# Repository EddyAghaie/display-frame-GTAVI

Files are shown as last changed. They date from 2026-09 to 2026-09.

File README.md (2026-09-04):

# display-frame-GTAVI
DIY PlayStation Gaming Wall Art made with a printed game cover, deep A4 picture frame, custom GIF player, 3D-printed disc holder, action figure, and printable game disc. Build your own unique gaming decoration with your favorite game. All 3D print files and project files are included in this repository.

# PlayStation Gaming Wall Art

<p align="center">
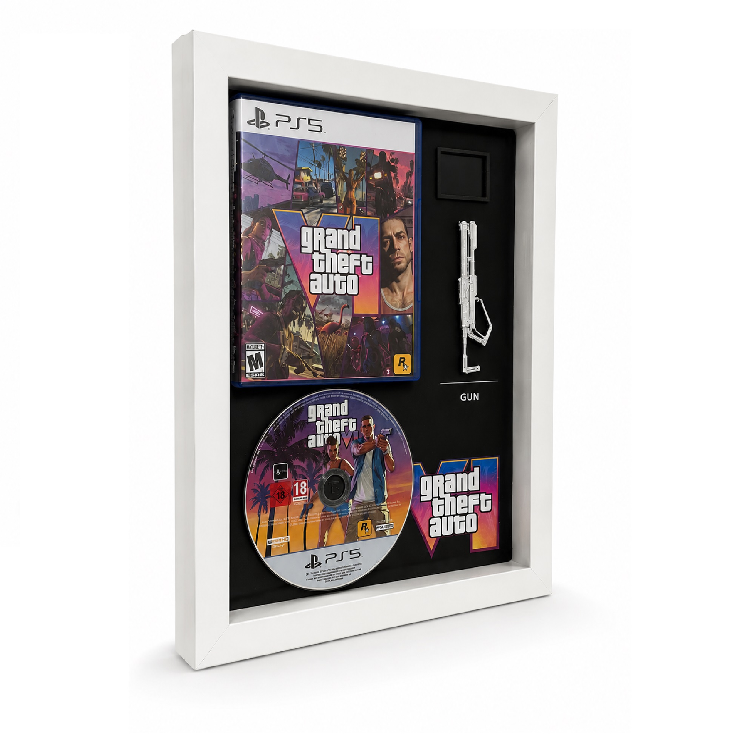
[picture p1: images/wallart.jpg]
  
</p>

DIY PlayStation Gaming Wall Art...
A DIY gaming wall art project made from a PlayStation game case, a printed game cover, a GIF player, and 3D-printed parts.

This project turns a simple game case into a unique gaming decoration with a small display that can play your favorite GIFs.

## Features

* PlayStation game case design
* Custom printed game cover
* Small GIF player with display
* 3D-printed disc holder
* 3D-printed action figure holder
* Custom printed game disc
* A4 deep picture frame
* Custom printed background
* Easy to build
* Low-cost project

## What You Need

* 1× PlayStation game case
* 1× Printed game cover — 270 × 166 mm
* 1× Printable game disc
* 1× GIF player
* 1× A4 deep picture frame
* 1× Printed game background
* 1× 3D-printed disc holder
* 1× 3D-printed action figure
* Double-sided tape
* Glue

## GIF Player

The GIF player is based on an ESP32 and a small display.

You can find the complete GIF player project, including the code, PCB files, wiring, and other files, in my previous GitHub project.

## 3D Print Files

All the 3D-printable files for this project are included in this repository.

You can download the files, print the parts, and build your own gaming wall art.

## Assembly

The project is made in a few simple steps:

1. Print the game cover.
2. Prepare the PlayStation game case.
3. Assemble the printed cover and game case.
4. Prepare the A4 picture frame.
5. Cut the display opening in the back of the frame.
6. Attach the printed background.
7. Install the GIF player.
8. Add the 3D-printed parts.
9. Assemble everything together.
10. Add your favorite game disc and action figure.

## Cost

The project is designed to be low-cost and easy to build.

The GIF player itself costs less than **$6** to build, depending on the components and prices in your area.

## Customize Your Project

You can use any PlayStation game you like.

Change the game cover, background, disc, GIFs, and action figure to create your own custom gaming wall art.

## Files

This repository includes:

* 3D print files
* Game cover template
* Background files
* Printable disc files
* Assembly files
* Project images
* Instructions

## Video Tutorial

Watch the full build video on my YouTube channel to see how I made this project from start to finish.

**EDDYSTUDIO_LAB**

If you build your own version, feel free to share it!

## License

This project is provided for personal and educational use.

Please check the licenses of any third-party game artwork, characters, logos, or other copyrighted materials before redistributing or selling your own version.

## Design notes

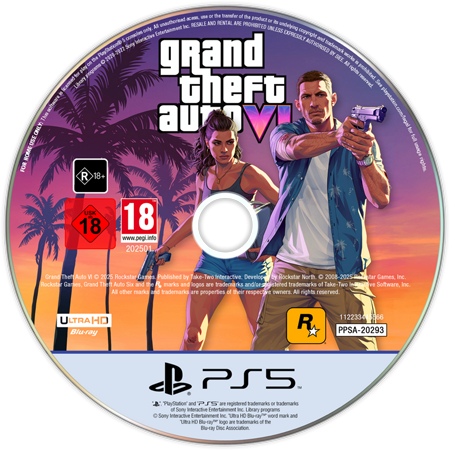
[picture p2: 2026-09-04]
GTA VI IMAGE: PRINT FILE/gta6-ps5-disc-fan-mad-concept-s.png

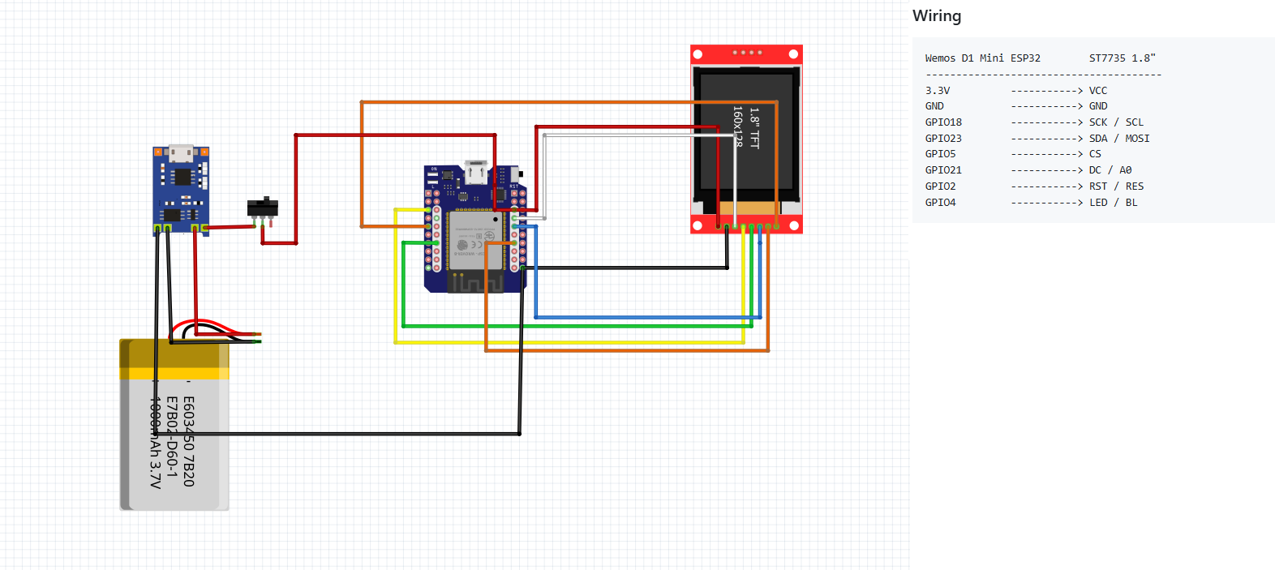
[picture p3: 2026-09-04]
GIFPLAYER/schema.PNG

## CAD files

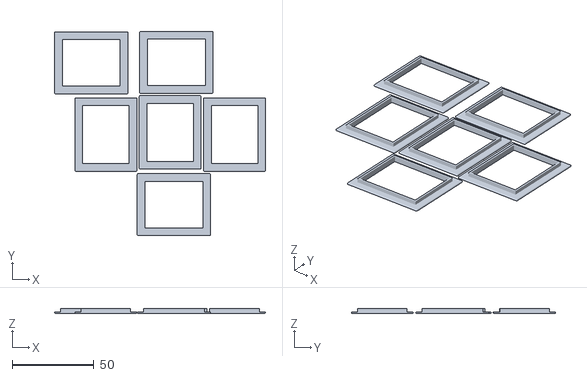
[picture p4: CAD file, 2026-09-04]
3DFILE/frame.stl
129.3 x 125.2 x 3.00

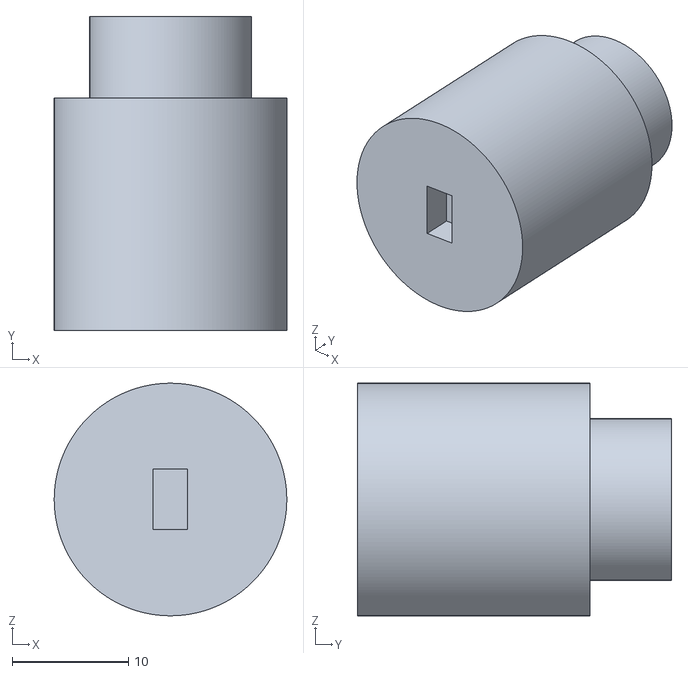
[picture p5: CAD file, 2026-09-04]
3DFILE/ring cd.stl
20.0 x 27.0 x 20.0

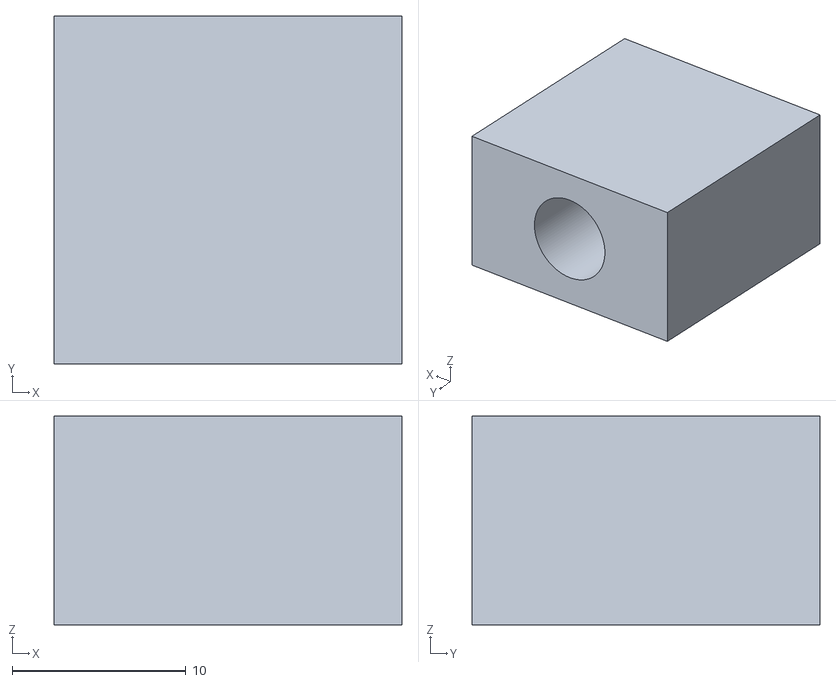
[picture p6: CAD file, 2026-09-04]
3DFILE/stand hole.stl
20.0 x 20.0 x 12.0

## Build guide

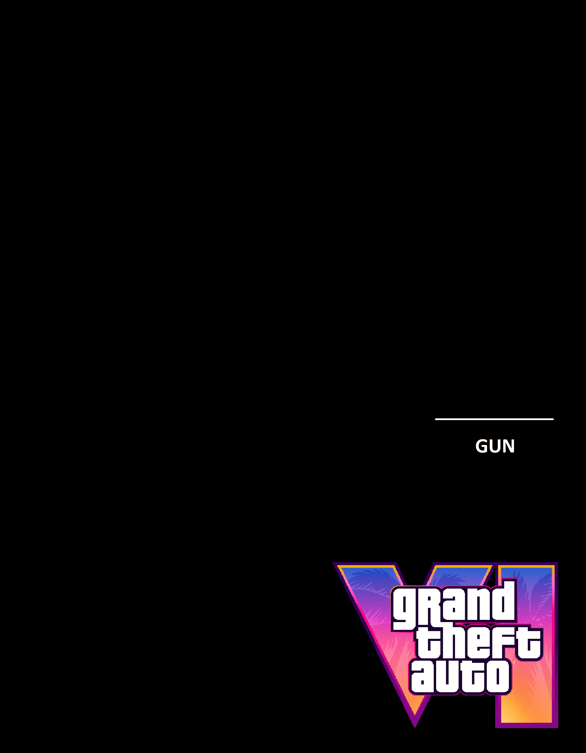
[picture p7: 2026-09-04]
GTA VI IMAGE: PRINT FILE/background.png

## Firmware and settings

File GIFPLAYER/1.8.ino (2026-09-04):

/*
  ====================================================================
  GifFrame - ESP32 + ST7735 1.8" (160x128 Landscape) WiFi Image/GIF Frame
  ====================================================================
  پین‌بندی نهایی:
    SDA (MOSI) = GPIO23
    SCK        = GPIO18
    CS         = GPIO5
    LED (BL)   = GPIO4
    RESET      = GPIO2
    DC         = GPIO21
    VCC -> 3.3V , GND -> GND

  کتابخانه‌های لازم (از Library Manager نصب کنید):
    - Adafruit GFX Library
    - Adafruit ST7735 and ST7789 Library (+ Adafruit BusIO)
    - ESPAsyncWebServer + AsyncTCP  (فورک ESP32Async از گیت‌هاب - ZIP)
    - LittleFS (داخل هسته ESP32)
    - Preferences (داخل هسته ESP32)
    - QRCodeGen.h / QRCodeGen.c (کنار فایل .ino - فایل‌های ricmoo/QRCode با اصلاح bool)

  نکته: AnimatedGIF دیگر لازم نیست. پردازش/ریسایز کاملاً سمت گوشی
        با جاوااسکریپت خالص (بدون نیاز به اینترنت/CDN) انجام می‌شود
        و یک فرمت باینری سبک سفارشی به نام "GFA1" به دستگاه ارسال می‌شود.

  منطق کلی:
    1) بوت اول (هیچ فایلی ذخیره نشده): صفحه QR1 با پس‌زمینه سفید نشان داده
       می‌شود - برای اتصال خودکار گوشی به وای‌فای دستگاه (بدون پسورد).
    2) به محض اتصال یک کلاینت به AP (رویداد WiFi)، صفحه به QR2 با پس‌زمینه
       قرمز تغییر می‌کند که آدرس "http://192.168.4.1/" را کد کرده -
       با اسکن، صفحه تنظیمات مستقیماً در مرورگر گوشی باز می‌شود (بدون
       نیاز به Captive Portal، که در iOS محدودیت‌های زیادی دارد).
    3) صفحه‌ی وب: آپلود هر عکس/گیف از گالری گوشی + راهنمای انگلیسی برای
       افزودن به Home Screen یا ذخیره آدرس 192.168.4.1.
       مرورگر خودش عکس/گیف رو دیکود، cover (پر کردن کامل صفحه بدون فضای
       خالی) به 160x128 ریسایز، و به فرمت "GFA1" (هدر + فریم‌های RGB565
       خام) تبدیل و آپلود می‌کند.
    4) ESP32 فایل "/current.anim" را ذخیره و به‌صورت لوپ دائم پخش می‌کند؛
       از این لحظه صفحات QR دیگر نمایش داده نمی‌شوند.
    5) فکتوری ریست: شمارش 5 بار روشن/خاموش در بازه 10 ثانیه با Preferences (NVS)
       -> پاک کردن LittleFS و ریست تنظیمات (برگشت به صفحه QR1).

  فرمت فایل "/current.anim" (GFA1):
    بایت 0-3   : "GFA1"
    بایت 4-5   : width  (uint16, little-endian) -> باید برابر SCREEN_W باشد
    بایت 6-7   : height (uint16, little-endian) -> باید برابر SCREEN_H باشد
    بایت 8-9   : frameCount (uint16, little-endian)
    سپس به ازای هر فریم:
      2 بایت delay_ms (uint16, little-endian)
      width*height*2 بایت پیکسل RGB565 (هر پیکسل 2 بایت big-endian/wire order)

  ====================================================================
*/

#include <SPI.h>
#include <Adafruit_GFX.h>
#include <Adafruit_ST7735.h>
#include <FS.h>
#include <LittleFS.h>
#include <WiFi.h>
#include <ESPAsyncWebServer.h>
#include <Preferences.h>
#include "QRCodeGen.h" // کتابخانه QRCode (ricmoo) - فایل‌های QRCodeGen.h/.c باید کنار .ino باشن

// ---------------- پین‌بندی ----------------
#define TFT_CS   5
#define TFT_DC   21
#define TFT_RST  2
#define TFT_LED  4
// MOSI=23 (SDA), SCK=18 -> پیش‌فرض HSPI/VSPI روی ESP32 همین‌ها هستند

#define SCREEN_W 160
#define SCREEN_H 128

// اگر تصویر روی نمایشگر شیفت/کراپ/wrap شده دیده شد، این مقادیر را تغییر بده.
// 2,1 رایج‌ترین مقدار برای پنل‌های 1.8" ST7735 (132x162 GRAM روی پنل 128x160) است.
// مقادیر دیگری که می‌توان امتحان کرد: (0,0), (2,3), (1,2), (3,2), (4,0)
// با کد اولیه (offset=0,0) تصاویر کامل و بدون موج/کجی نمایش داده می‌شدن.
// تغییر این مقادیر باعث موج‌دار/کج‌شدن تصویر می‌شود - دست نزنید مگر مطمئن باشید.
#define COL_START 0
#define ROW_START 0

// X_OFFSET/Y_OFFSET برای تنظیم ریز (fine-tuning) اضافه، معمولاً 0 بماند.
#define X_OFFSET 0
#define Y_OFFSET 0

// کلاس کوچک مشتق‌شده فقط برای دسترسی به setColRowStart که در کتابخونه protected است
class Adafruit_ST7735_Custom : public Adafruit_ST7735 {
public:
  Adafruit_ST7735_Custom(int8_t cs, int8_t dc, int8_t rst) : Adafruit_ST7735(cs, dc, rst) {}
  void setOffset(int8_t col, int8_t row) { setColRowStart(col, row); }
};

Adafruit_ST7735_Custom tft = Adafruit_ST7735_Custom(TFT_CS, TFT_DC, TFT_RST);
AsyncWebServer server(80);
Preferences prefs;

String apSSID;

// از بخش پخش (پایین‌تر تعریف می‌شود) - برای جلوگیری از دست‌کاری صفحه در حین پخش فریم
extern volatile bool animPlaying;

// ====================================================================
//                     ۱) FACTORY RESET LOGIC
// ====================================================================
// با 5 بار روشن/خاموش در بازه 10 ثانیه از حافظه NVS، ریست فکتوری انجام می‌شود.
void checkFactoryReset() {
  prefs.begin("sysinfo", false);
  uint8_t bootCount = prefs.getUChar("bootcnt", 0);

  bootCount++;
  if (bootCount >= 5) {
    Serial.println("== FACTORY RESET TRIGGERED ==");
    prefs.putUChar("bootcnt", 0);
    prefs.end();

    // پاک کردن کامل LittleFS (شامل فریم فعال و تنظیمات)
    LittleFS.format();

    tft.fillScreen(ST77XX_BLACK);
    tft.setTextColor(ST77XX_WHITE);
    tft.setTextSize(1);
    tft.setCursor(10, 60);
    tft.println("Factory Reset...");
    delay(1500);
    ESP.restart();
    return;
  }

  prefs.putUChar("bootcnt", bootCount);
  prefs.end();
}

void resetBootCounterAfterTimeout() {
  static unsigned long startTime = millis();
  static bool done = false;
  if (!done && millis() - startTime > 10000) {
    prefs.begin("sysinfo", false);
    prefs.putUChar("bootcnt", 0);
    prefs.end();
    done = true;
  }
}

// ====================================================================
//                     ۲) صفحات QR (Landscape) - دو مرحله‌ای
// ====================================================================
// QR_VERSION=4 برای هر دو متن (WiFi config و URL) کافی است.
// سایز بافر = ((4*version+17)^2 + 7) / 8  ->  برای version=4: ((33*33)+7)/8 = 137
#define QR_VERSION 4
#define QR_BUFFER_SIZE 137
uint8_t qrcodeBuffer[QR_BUFFER_SIZE];

// رسم ماژول‌های QR در یک مستطیل مشخص
void drawQRModules(QRCode &qrcode, int offsetX, int offsetY, int pixelSize, uint16_t fg, uint16_t bg) {
  for (uint8_t y = 0; y < qrcode.size; y++) {
    for (uint8_t x = 0; x < qrcode.size; x++) {
      uint16_t color = qrcode_getModule(&qrcode, x, y) ? fg : bg;
      tft.fillRect(offsetX + x * pixelSize, offsetY + y * pixelSize, pixelSize, pixelSize, color);
    }
  }
}

// محاسبه‌ی اندازه و موقعیت QR وسط‌چین (هم افقی هم عمودی) با کمی فضا برای یک برچسب بالای آن
void computeQRLayoutCentered(QRCode &qrcode, int &offsetX, int &offsetY, int &pixelSize, int &totalSize, int topReserved) {
  const int sideMargin = 6;
  const int bottomMargin = 4;
  int availW = SCREEN_W - sideMargin * 2;
  int availH = SCREEN_H - topReserved - bottomMargin;

  pixelSize = min(availW / qrcode.size, availH / qrcode.size);
  if (pixelSize < 1) pixelSize = 1;
  totalSize = pixelSize * qrcode.size;

  offsetX = (SCREEN_W - totalSize) / 2 + X_OFFSET;
  offsetY = topReserved + (SCREEN_H - topReserved - totalSize) / 2 + Y_OFFSET;
}

// رسم یک برچسب کوچک وسط‌چین در بالای صفحه
void drawTopLabel(const char* text, uint16_t fg, uint16_t bg) {
  tft.setTextColor(fg, bg);
  tft.setTextSize(1);
  int textW = strlen(text) * 6; // هر کاراکتر در سایز 1 حدوداً 6px
  int x = (SCREEN_W - textW) / 2;
  if (x < 0) x = 0;
  tft.setCursor(x, 4);
  tft.println(text);
}

// -------- مرحله ۱: صفحه اتصال به وای‌فای (پس‌زمینه سفید) --------
// -------- مرحله ۱: صفحه اتصال به وای‌فای (پس‌زمینه سفید) --------
void drawConnectScreen() {
  tft.fillScreen(ST77XX_WHITE);

  String qrText = "WIFI:T:nopass;S:" + apSSID + ";;";
  QRCode qrcode;
  qrcode_initText(&qrcode, qrcodeBuffer, QR_VERSION, ECC_MEDIUM, qrText.c_str());

  const int topReserved = 16;
  int offsetX, offsetY, pixelSize, totalSize;
  computeQRLayoutCentered(qrcode, offsetX, offsetY, pixelSize, totalSize, topReserved);

  drawTopLabel("WiFi Connect", ST77XX_BLACK, ST77XX_WHITE);
  drawQRModules(qrcode, offsetX, offsetY, pixelSize, ST77XX_BLACK, ST77XX_WHITE);
}

// -------- مرحله ۲: صفحه باز کردن صفحه تنظیمات (پس‌زمینه قرمز) --------
void drawOpenPageScreen() {
  tft.fillScreen(ST77XX_RED);

  String url = "http://192.168.4.1/";
  QRCode qrcode;
  qrcode_initText(&qrcode, qrcodeBuffer, QR_VERSION, ECC_MEDIUM, url.c_str());

  const int topReserved = 16;
  int offsetX, offsetY, pixelSize, totalSize;
  computeQRLayoutCentered(qrcode, offsetX, offsetY, pixelSize, totalSize, topReserved);

  // کادر سفید پشت QR برای کنتراست بهتر روی پس‌زمینه قرمز
  tft.fillRect(offsetX - 4, offsetY - 4, totalSize + 8, totalSize + 8, ST77XX_WHITE);

  drawTopLabel("Upload Page", ST77XX_WHITE, ST77XX_RED);
  drawQRModules(qrcode, offsetX, offsetY, pixelSize, ST77XX_BLACK, ST77XX_WHITE);
}

// ====================================================================
//                     ۳) راه‌اندازی WiFi AP (بدون Captive Portal)
// ====================================================================

// وقتی هیچ فایل anim پخش نمی‌شود (هنوز در مرحله تنظیمات هستیم)، با اتصال/قطع
// کلاینت‌ها بین صفحه QR1 (اتصال) و QR2 (باز کردن صفحه تنظیمات) سوییچ می‌کنیم.
void onWiFiAPEvent(WiFiEvent_t event) {
  if (animPlaying) return; // اگه قاب در حال پخشه، صفحه رو دست نزن

  if (event == ARDUINO_EVENT_WIFI_AP_STACONNECTED) {
    drawOpenPageScreen();
  } else if (event == ARDUINO_EVENT_WIFI_AP_STADISCONNECTED) {
    if (WiFi.softAPgetStationNum() == 0) {
      drawConnectScreen();
    }
  }
}

void setupWiFiAP() {
  uint8_t mac[6];
  WiFi.macAddress(mac);
  char suffix[5];
  sprintf(suffix, "%02X%02X", mac[4], mac[5]);
  apSSID = "TABLO" + String(suffix);

  WiFi.onEvent(onWiFiAPEvent);
  WiFi.mode(WIFI_AP);
  WiFi.softAP(apSSID.c_str()); // بدون پسورد -> open network

  IPAddress apIP = WiFi.softAPIP(); // معمولاً 192.168.4.1

  drawConnectScreen();
  Serial.println("AP started: " + apSSID);
  Serial.println("IP: " + apIP.toString());
}

// ====================================================================
//                     ۴) پخش فایل GFA1 (لوپ دائم)
// ====================================================================
File animFile;
uint16_t animW = 0, animH = 0, animFrameCount = 0;
const uint32_t ANIM_DATA_START = 10;
uint16_t animFrameIndex = 0;
unsigned long animLastFrameTime = 0;
uint16_t animCurrentDelay = 0;
volatile bool newAnimAvailable = false;
volatile bool animPlaying = false;

bool openCurrentAnim() {
  if (animFile) animFile.close();
  if (!LittleFS.exists("/current.anim")) return false;

  animFile = LittleFS.open("/current.anim", "r");
  if (!animFile) return false;

  uint8_t header[10];
  if (animFile.read(header, 10) != 10) { animFile.close(); return false; }
  if (header[0] != 'G' || header[1] != 'F' || header[2] != 'A' || header[3] != '1') {
    Serial.println("Invalid anim file header");
    animFile.close();
    return false;
  }

  animW = header[4] | (header[5] << 8);
  animH = header[6] | (header[7] << 8);
  animFrameCount = header[8] | (header[9] << 8);

  if (animW != SCREEN_W || animH != SCREEN_H || animFrameCount == 0) {
    Serial.println("Anim size mismatch or empty");
    animFile.close();
    return false;
  }

  animFrameIndex = 0;
  animFile.seek(ANIM_DATA_START);
  tft.fillScreen(ST77XX_BLACK);
  animLastFrameTime = 0;
  animCurrentDelay = 0; // فریم اول فوری نمایش داده شود
  return true;
}

void playAnimTick() {
  if (!animPlaying || !animFile) return;
  if (millis() - animLastFrameTime < animCurrentDelay) return;

  uint8_t db[2];
  if (animFile.read(db, 2) != 2) {
    // پایان فایل -> برگرد به فریم اول (لوپ دائم)
    animFile.seek(ANIM_DATA_START);
    animFrameIndex = 0;
    if (animFile.read(db, 2) != 2) return; // فایل خراب
  }
  uint16_t delayMs = db[0] | (db[1] << 8);
  if (delayMs < 20) delayMs = 100;

  static uint16_t lineBuf[SCREEN_W];

  tft.startWrite();
  tft.setAddrWindow(X_OFFSET, Y_OFFSET, animW, animH);
  for (uint16_t row = 0; row < animH; row++) {
    size_t need = (size_t)animW * 2;
    size_t got = animFile.read((uint8_t*)lineBuf, need);
    if (got != need) {
      memset(lineBuf, 0, sizeof(lineBuf));
    }
    tft.writePixels(lineBuf, animW, false, true); // bigEndian=true: بایت‌ها همان‌طور که نوشته شده‌اند ارسال می‌شوند
  }
  tft.endWrite();

  animFrameIndex++;
  if (animFrameIndex >= animFrameCount) {
    animFrameIndex = 0;
    animFile.seek(ANIM_DATA_START);
  }

  animLastFrameTime = millis();
  animCurrentDelay = delayMs;
}

// ====================================================================
//                     ۵) صفحه وب (HTML/CSS/JS کاملاً آفلاین)
// ====================================================================
const char index_html[] PROGMEM = R"rawliteral(
<!DOCTYPE html>
<html lang="fa" dir="rtl">
<head>
<meta charset="UTF-8">
<meta name="viewport" content="width=device-width, initial-scale=1.0, viewport-fit=cover">
<title>GifFrame</title>
<link rel="manifest" href="/manifest.json">
<link rel="apple-touch-icon" href="/icon.png">
<meta name="apple-mobile-web-app-capable" content="yes">
<meta name="apple-mobile-web-app-status-bar-style" content="black-translucent">
<meta name="theme-color" content="#111111">
<style>
  * { box-sizing: border-box; -webkit-tap-highlight-color: transparent; }
  body {
    margin:0; font-family: -apple-system, 'Segoe UI', Tahoma, sans-serif;
    background: linear-gradient(180deg,#1a1a2e,#0f0f1a); color:#fff; min-height:100vh;
  }
  header {
    padding: 18px 16px; text-align:center; font-size:20px; font-weight:700;
    background: rgba(255,255,255,0.05); backdrop-filter: blur(10px);
    position: sticky; top:0; z-index:10;
  }
  .container { padding: 16px; max-width: 600px; margin: 0 auto; }
  .upload-box {
    border: 2px dashed #555; border-radius: 16px; padding: 30px 16px;
    text-align: center; margin-bottom: 20px; transition: 0.2s;
    background: rgba(255,255,255,0.03);
  }
  .upload-box.dragover { border-color:#6c5ce7; background: rgba(108,92,231,0.1); }
  .upload-box input { display:none; }
  .upload-box label {
    display:inline-block; padding: 12px 24px; border-radius: 12px;
    background: linear-gradient(135deg,#6c5ce7,#a29bfe); color:#fff;
    font-weight:600; cursor:pointer; margin-top:10px;
  }
  .progress-wrap {
    width:100%; height:10px; background:rgba(255,255,255,0.08);
    border-radius:6px; overflow:hidden; margin-top:14px; display:none;
  }
  .progress-bar {
    height:100%; width:0%; background:linear-gradient(135deg,#6c5ce7,#a29bfe);
    transition: width 0.15s;
  }
  .status {
    text-align:center; padding:10px; border-radius:10px; margin-bottom:14px;
    background: rgba(0,255,150,0.1); color:#7fffd4; font-size:14px; display:none;
  }
  .status.show { display:block; }
  .info-banner {
    background: rgba(108,92,231,0.12); border: 1px solid rgba(108,92,231,0.35);
    border-radius: 12px; padding: 12px 14px; margin-bottom: 14px;
    font-size: 13px; line-height: 1.7; text-align: left; direction: ltr;
    position: relative;
  }
  .info-banner b { color: #c2b8ff; }
  .info-banner .close-btn {
    position: absolute; top: 6px; right: 8px; background: none; border: none;
    color: #aaa; font-size: 16px; cursor: pointer; line-height: 1;
  }
  .preview { margin-top:14px; text-align:center; }
  .preview canvas {
    max-width:100%; border-radius:10px; image-rendering: pixelated;
    background:#000; border:1px solid rgba(255,255,255,0.1);
  }
</style>
</head>
<body>
<header>📺 GifFrame</header>
<div class="container">

  <div class="info-banner" id="infoBanner">
    <button class="close-btn" onclick="document.getElementById('infoBanner').style.display='none'">✕</button>
    📌 <b>Tip:</b> Add this page to your Home Screen, or save this address for next time:<br>
    <b>http://192.168.4.1</b>
  </div>

  <div class="status" id="status"></div>

  <div class="upload-box" id="dropZone">
    <div>یک عکس یا GIF بکش اینجا یا انتخاب کن</div>
    <label for="fileInput">انتخاب از گالری</label>
    <input type="file" id="fileInput" accept="image/*">
    <div class="progress-wrap" id="progressWrap">
      <div class="progress-bar" id="progressBar"></div>
    </div>
    <div class="preview" id="preview"></div>
  </div>

</div>

<script>
// ابعاد نمایشگر (Landscape)
const SCREEN_W = 160;
const SCREEN_H = 128;

// بِزِل فیزیکی پنل کمی از ارتفاع بالا/پایین رو می‌پوشونه. برای جلوگیری از
// کراپ‌شدن محتوای مهم تصویر، کاور رو بر اساس یک "ارتفاع ایمن" کوچک‌تر
// محاسبه می‌کنیم (با حاشیه‌ی سیاه ناچیز که زیر بزل پنهان می‌شه).
// اگه هنوز کمی بالا/پایین کراپ بود، این عدد رو کمتر کن (مثلاً 112).
// اگه حاشیه سیاه قابل‌توجه دیدی، بیشترش کن (مثلاً 124).
const VISIBLE_H = 118;

const MAX_FRAMES = 30; // حداکثر فریم خروجی برای جلوگیری از حجم زیاد

function showStatus(msg, ok=true) {
  const s = document.getElementById('status');
  s.textContent = msg;
  s.style.background = ok ? 'rgba(0,255,150,0.1)' : 'rgba(255,80,80,0.15)';
  s.style.color = ok ? '#7fffd4' : '#ff7f7f';
  s.classList.add('show');
}

function setProgress(pct) {
  const wrap = document.getElementById('progressWrap');
  const bar = document.getElementById('progressBar');
  if (pct === null) { wrap.style.display = 'none'; return; }
  wrap.style.display = 'block';
  bar.style.width = pct + '%';
}

// محاسبه سایز "cover": عرض کامل صفحه + ارتفاع "ایمن" (VISIBLE_H) رو پر می‌کند
function fitSize(srcW, srcH) {
  const scale = Math.max(SCREEN_W / srcW, VISIBLE_H / srcH);
  const w = Math.round(srcW * scale);
  const h = Math.round(srcH * scale);
  const x = Math.round((SCREEN_W - w) / 2); // معمولاً <= 0
  const y = Math.round((SCREEN_H - h) / 2); // ممکنه حاشیه کوچک ایجاد کند
  return { w, h, x, y };
}

// ============================================================
// ====== رمزگشای GIF خالص جاوااسکریپت (بدون کتابخونه خارجی) ======
// ============================================================
function parseGifFile(buffer) {
  const data = new Uint8Array(buffer);
  let p = 0;
  function readByte(){ return data[p++]; }
  function readU16(){ const v = data[p] | (data[p+1]<<8); p+=2; return v; }

  if (!(data[0]===0x47 && data[1]===0x49 && data[2]===0x46)) {
    throw new Error('فایل GIF معتبر نیست');
  }
  p = 6;
  const screenW = readU16();
  const screenH = readU16();
  const packed = readByte();
  const gctFlag = (packed & 0x80) !== 0;
  const gctSize = 2 << (packed & 0x07);
  readByte(); // background color index
  readByte(); // aspect ratio
  let gct = null;
  if (gctFlag) {
    gct = [];
    for (let i=0;i<gctSize;i++) gct.push([data[p++],data[p++],data[p++]]);
  }

  const frames = [];
  let gceDelay = 100, gceTransparent = -1, gceDisposal = 0;

  while (p < data.length) {
    const block = readByte();
    if (block === 0x21) { // Extension
      const label = readByte();
      if (label === 0xF9) { // Graphic Control Extension
        readByte(); // block size = 4
        const packed2 = readByte();
        gceDisposal = (packed2 >> 2) & 0x07;
        const hasTransparency = (packed2 & 0x01) !== 0;
        gceDelay = readU16() * 10;
        if (gceDelay === 0) gceDelay = 100;
        const transIdx = readByte();
        gceTransparent = hasTransparency ? transIdx : -1;
        readByte(); // terminator
      } else {
        let size;
        while ((size = readByte()) !== 0) p += size;
      }
    } else if (block === 0x2C) { // Image Descriptor
      const left = readU16();
      const top = readU16();
      const width = readU16();
      const height = readU16();
      const packed3 = readByte();
      const lctFlag = (packed3 & 0x80) !== 0;
      const interlace = (packed3 & 0x40) !== 0;
      const lctSize = 2 << (packed3 & 0x07);
      let lct = null;
      if (lctFlag) {
        lct = [];
        for (let i=0;i<lctSize;i++) lct.push([data[p++],data[p++],data[p++]]);
      }
      const minCodeSize = readByte();
      const bytes = [];
      let size;
      while ((size = readByte()) !== 0) {
        for (let i=0;i<size;i++) bytes.push(data[p++]);
      }
      let indices = lzwDecode(bytes, minCodeSize, width*height);
      if (interlace) indices = deinterlace(indices, width, height);

      frames.push({
        left, top, width, height,
        colorTable: lct || gct || [[0,0,0]],
        transparent: gceTransparent,
        disposal: gceDisposal,
        delay: gceDelay,
        indices
      });
      gceDelay = 100; gceTransparent = -1; gceDisposal = 0;
    } else if (block === 0x3B) {
      break; // Trailer
    } else {
      break; // ناشناخته - برای جلوگیری از حلقه بی‌پایان متوقف شو
    }
  }
  return { width: screenW, height: screenH, frames };
}

function lzwDecode(bytes, minCodeSize, pixelCount) {
  const clearCode = 1 << minCodeSize;
  const eoiCode = clearCode + 1;
  let codeSize, dict;

  function resetDict() {
    dict = [];
    for (let i=0;i<clearCode;i++) dict[i] = [i];
    dict[clearCode] = [];
    dict[eoiCode] = [];
    codeSize = minCodeSize + 1;
  }
  resetDict();

  const output = new Uint8Array(pixelCount);
  let outPos = 0;
  let bitPos = 0;
  const totalBits = bytes.length * 8;

  function readCode() {
    let code = 0;
    for (let i=0;i<codeSize;i++) {
      if (bitPos >= totalBits) return eoiCode;
      const byteIndex = bitPos >> 3;
      const bitIndex = bitPos & 7;
      if ((bytes[byteIndex] >> bitIndex) & 1) code |= (1 << i);
      bitPos++;
    }
    return code;
  }

  let prevCode = -1;
  while (outPos < pixelCount) {
    const code = readCode();
    if (code === clearCode) { resetDict(); prevCode = -1; continue; }
    if (code === eoiCode) break;

    let entry;
    if (dict[code] !== undefined) {
      entry = dict[code];
    } else if (code === dict.length && prevCode !== -1) {
      entry = dict[prevCode].concat([dict[prevCode][0]]);
    } else {
      break; // داده خراب
    }

    for (let i=0;i<entry.length && outPos<pixelCount;i++) output[outPos++] = entry[i];

    if (prevCode !== -1 && dict.length < 4096) {
      dict[dict.length] = dict[prevCode].concat([entry[0]]);
      if (dict.length === (1<<codeSize) && codeSize < 12) codeSize++;
    }
    prevCode = code;
  }
  return output;
}
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
void loop() {
  resetBootCounterAfterTimeout();

  if (newAnimAvailable) {
    newAnimAvailable = false;
    if (openCurrentAnim()) {
      animPlaying = true;
    }
  }

  playAnimTick();

  delay(1);
}
